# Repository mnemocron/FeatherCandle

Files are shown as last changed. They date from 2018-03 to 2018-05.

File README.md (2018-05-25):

# Feather Candle "_Guet Nacht - I Love You_"
## 15x7 LED matrix candle based on Adafruit Feather HUZZAH (ESP8266)

---

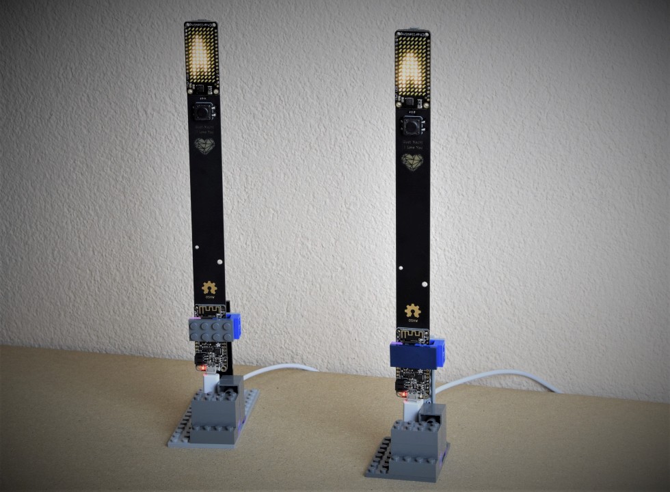
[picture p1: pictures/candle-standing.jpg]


## Introduction

This electronic project is intended as a romantic gimmik for two long distance lovers.
The candle is connected to the io.adafruit.com cloud over WiFi.

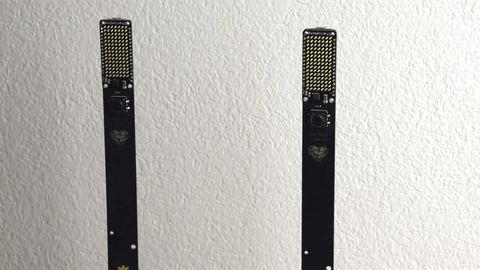
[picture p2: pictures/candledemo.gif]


> Whenever one person turns on their own candle, the candle of their lover - on the other side of the world - will light up as well.

The project is built around the Adafruit Feather boards and uses the 15x7 LED matrix and the WiFi enabled Feather HUZZAH board based on the ESP8266 microcontroller. The IoT handling is built around the MQTT service of [io.adafruit.com](https://io.adafruit.com).

### The Name

**_"Guet Nacht"_** is wishing a good night in Swiss German. When I was working on this project I said good night to my loved person by telling them _"Guet Nacht - I love you"_. Ultimately I decided that this is the codename for this project.

---

## Hardware

There are three different variants for the hardware configuration which ultimately determines the functionality and software capabilities. **Yes you can build just the candle without WiFi.**

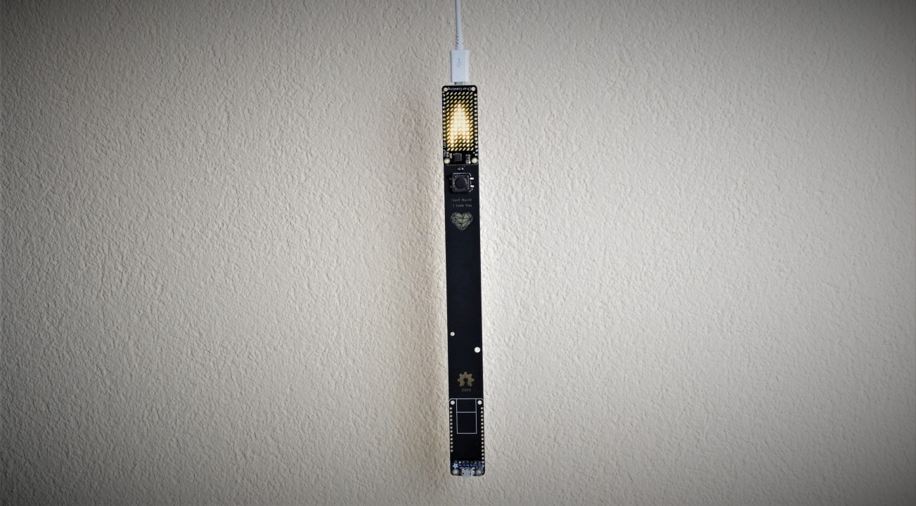
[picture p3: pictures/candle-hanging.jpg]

The candle can also be hung from the ceiling.

### Variant 1: Trinket (just the candle)

This is the most simple and straight forward variant. The essential parts are the [Adafruit 15x7 CharliePlex LED Matrix FeatherWing](https://www.adafruit.com/product/3163) and the [Adafruit Trinket M0](https://www.adafruit.com/product/3500).
This variant is just the candle powered over micro USB.
The micro USB connector is at the top (where the flame is) so the candle could be hanged from the ceiling. Alternatively you can add a [USB Micro-B Breakout Board](https://www.adafruit.com/product/1833) at the bottom of the board to power the candle at the socket.

### Variant 2: Feather (just the candle)

This variant is driven by any Feather board capable of compiling the candle animation sketch. The Feather boards provide an on-board battery charger. At the back of the candle's PCB there is space for a [Keystone 1042P](http://www.keyelco.com/product.cfm/product_id/918) battery holder for a 18650 3.7V battery (this feature is not tested).

### Variant 3: HUZZAH (WiFi enabled)

This is the original Idea. The Trinket holds the code for the flame animation while the Feather HUZZAH is connected to the Adafruit IO cloud. This variant can also be powered by a battery like variant 2. 

##### Battery

This feature remains **untested**. 
Also note that the ESP8266 uses a significant ammount of power, up to 170mA when transmitting data over Wifi ([source](https://bbs.espressif.com/viewtopic.php?t=133)). This may result in very short battery service life).

---

### Building Variant 3

#### Bill of materials (BOM)

This is the partlist for the WiFi enabled candle. 

| Description | Value | Manufacturer | Pcs. | Part. Nr. (mouser) | price (estimation) |
|---|---:|---|-----:|---:|---:|
| Candle PCB | - | - | 1 |  | $ 10.00 |
| 15x7 CharliePlex LED Matrix FeatherWing (warm white) | - | [Adafruit (3163)](https://www.adafruit.com/product/3163) | 1 | [485-3163](https://www.mouser.com/ProductDetail/Adafruit/3163?qs=%2fha2pyFaduh%252brbpYDT4hI1KcasFFaXTHrw3K2WUgkuI%3d) | $ 13.30 |
| Feather HUZZAH with ESP8266 WiFi | - | [Adafruit (2821)](https://www.adafruit.com/product/2821) | 1 | [485-2821](https://www.mouser.com/ProductDetail/Adafruit/2821?qs=%2fha2pyFadujIGPK6Sj3t4nFuChuwEnz5Imbr6Do1gT8%3d) | $ 18.00 |
| Trinket M0 | - | [Adafruit (3500)](https://www.adafruit.com/product/3500) | 1 | [485-3500](https://www.mouser.com/ProductDetail/Adafruit/3500?qs=%2fha2pyFadugsjdovVS3NFiBTcocohBou1VlJ%2f0Oc5Cc%3d) | $ 9.20 |
| 18650 battery clip SMT | - | [Keystone Electronics](http://www.keyelco.com/product.cfm/product_id/918) | (1) | [534-1042P](https://www.mouser.com/ProductDetail/Keystone-Electronics/1042P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) | $ 3.10 |
| 18650 Li-Ion battery 3.7V | - | - | (1) |  |  |
| Resistor SMD 1206 | 10k | - | 2 | 
 | $ 0.10 |
| Resistor SMD 1206 | 330R | - | 1 |  | $ 0.10 |
| LED 0805 | - | - | 1 |  |  |
| Pushbutton SMD 12mm | - | - | 1 | eg. [611-PTS125SK43SMTR2](https://www.mouser.com/ProductDetail/611-PTS125SK43SMTR2) | $ 0.50 |
| Pushbutton SMD 6.2mm | - | - | 1 | eg. [611-KSC701GLFS](https://www.mouser.com/ProductDetail/611-KSC701GLFS) | $ 0.50 |
| Capacitor SMD 1206 | 100uF | - | (2) |  |
| Capacitor SMD 0805 | 0.1uF | - | (2) |  |
| USB Micro-B Breakout Board | - |[Adafruit (1833)](https://www.adafruit.com/product/1833) | (1) | [485-1833](https://www.mouser.com/ProductDetail/Adafruit/1833?qs=sGAEpiMZZMsMyYRRhGMFNlzK0q9uz4bUWJaCPx97HuA%3d) | $ 1.50 |
| **Total** * |  |  |  |  | **~$ 50.00** |

> (* The prices are just an estimation. Especially the PCB can only be ordered in larger quantities (>5 pcs).)

> **Important:** The above parts are just for **one** board. In order to build the two connected candles each component is required twice the ammount listed.

> **Notes** 
> - You can either place a 12mm or a 6.2mm push button on the front. (You also need a 6.2mm button on the back).
> - The USB Micro-B Breakout Board is optional for the **variants 1 & 2** (not required on variant 3)
> - **optional**: the capacitors are not required
> - **optional**: the battery holder and the 18650 battery are optional (only work on a **feather variant (2 & 3)**)

#### PCB

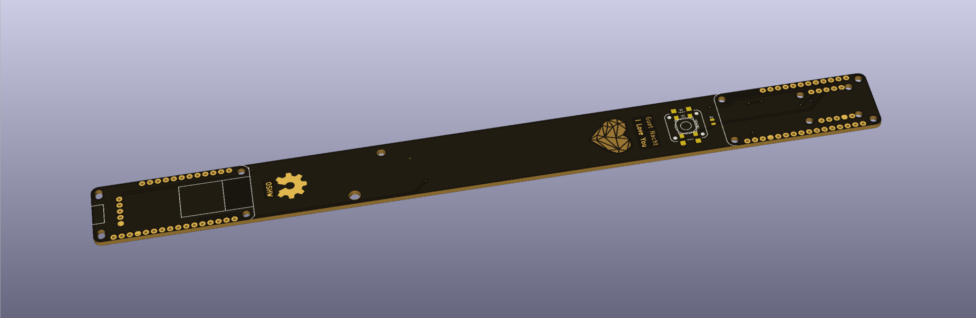
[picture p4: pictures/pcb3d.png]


You can download the manufacturing files (Gerbers) and use them to order the PCBs from a PCB manufacturer of choice. I recommend using **black solder mask** and **ENIG** surfacing.

Places where you can order custom circuit boards (selection):

> - [OSH Park](https://oshpark.com/)
> - [Aisler](https://aisler.net/products/boards)
> - [DirtyPCBs](http://dirtypcbs.com/store/pcbs)
> - [Elecrow](https://www.elecrow.com/pcb-manufacturing.html)
> - [JLCPCB](https://jlcpcb.com/quote)
> - [PCBCart](https://www.pcbcart.com/)
> - ([Aliexpress](https://www.aliexpress.com/category/521/pcb-pcba.html))

---

## Software

Setting up the Arduino IDE:

> - Download the [Arduitno IDE](https://www.arduino.cc/en/Main/Software)
> - How to up the [Adafruit Trinket M0](https://learn.adafruit.com/adafruit-trinket-m0-circuitpython-arduino/arduino-ide-setup)
> - How to up the [Adafruit Feather HUZZAH](https://learn.adafruit.com/adafruit-feather-huzzah-esp8266/using-arduino-ide)

#### Libraries

The following libraries are required to compile the software in the Arduino IDE.

> - [ESP8266 Arduino](https://github.com/esp8266/Arduino) 
> - [Adafruit IS31FL3731](https://github.com/adafruit/Adafruit_IS31FL3731) 
> - [Adafruit MQTT](https://github.com/adafruit/Adafruit_MQTT_Library) 
> - [Arduino Json](https://github.com/bblanchon/ArduinoJson) 
> - [Wifi Manager](https://github.com/tzapu/WiFiManager) 

### `FeatherCandleTrinket.ino`

This is the Arduino code for the Trinkete M0 which you will need for Variants 1 and 3.

**Note for Variant 1** (just the candle):
You might need to comment the `pinMode(PIN_ONOFF_WEB, INPUT);` on `line 68` so that the input isn't floating and randomly switching the flame on and off.

### `FeatherCandleFeather.ino`

This is the Arduino code soley for Variant 2 where the matrix is powered by any Feather microcontroller board.

### `FeatherCandleHuzzah.ino`

This is the Arduino code you need for the WiFi enabled Variant 3. This goes to the Feather HUZZAH board to connect to the Adafruit IO cloud and control the Trinket M0.

---

## Manual

### Setup the candle (WiFi)

The first time you turn on the candle you will have to configure the WiFi and the MQTT parameters. Luckily the software has a configuration portal built in, so you won't have to hardcode these parameters into the Arduino file.

> This way you can give away a candle to someone who does not know how to program.

### Signing up for Adafruit IO

You need to:
- create an Adafruit account
- log in to [io.adafruit.com](https://io.adafruit.com)
- create a new feed called `candle`

You need the following values to continue:
- `username` (find it on [accounts.adafruit.com](https://accounts.adafruit.com/))
- `key` (find it on [io.adafruit.com](https://learn.adafruit.com/mqtt-adafruit-io-and-you/getting-started-on-adafruit-io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))
- `feed` (the feed your just created: `candle`)

You can find more detailed instructions on how to get started with Adafruit IO on Adafruit's learning platform: [learn.adafruit.com](https://learn.adafruit.com/mqtt-adafruit-io-and-you/getting-started-on-adafruit-io)

**If you give away one candle to your lover:**

> **Important** Both candles require the same values for `username` / `key` / `feed` in order to be synchronized.

Your partner does not require an Adafruit account. Just give them your own `username` / `key` / `feed` so that they can set up their candle as follows:

#### To start the candle in configuration mode:

Hold the button on the back of the candle and turn on the feather candle. You can do this two ways:
- hold the button on the back then plug in the USB connector to power the device on
- hold the button on the back then press the reset button on the Feather HUZZAH itself while power is already on

finally release the button on the back.

Take your phone or computer and search for WiFi networks. You should see a network called `Feather Candle` - the password is `iloveyou`.

If you have successfully connected to the access point it should direct you to a "sign-in" page. If this does not happen just open your browser and open the webpage [10.0.1.1](http://10.0.1.1). On this page you have 4 buttons available.

##### `Info`

This page shows you the MAC address and other information about the ESP8266 that is on the Feather HUZZAH.

##### `Configure WiFi`

In the most cases this is the only page that you will need.

Choose a WiFi network on the list of available networks and enter the password.

**The ESP8266 only works with 2.4GHz networks.**

On this page you have a bunch of other values that you can configure.

| Name | Description | Default | need to change? |
|---|---|---:|---|
| `mqtt_server` | address to the MQTT server | `io.adafrtuit.com` | no |
| `mqtt_port` | MQTT server port | `1883` | no |
| `aio_key` | Adafruit IO key |  | yes |
| `aio_username` | Adafruit IO username |  | yes |
| `aio_feed` | Adafruit IO feed | `candle` | optional (*) |
| `aio_poll_interval` | interval to check for changes in [s] | `3` | optional (**) |
| `aio_last_will` | last value to send on disconnect | `0` | optional |

(*) the name of your Adafruit IO feed

(**) not implemented yet, see issues - default value is 3 seconds

---

## Inspiration

### mori.london

>mori.london sets out to define a completely new category of LED lighting: playful, emotional, atmospheric and elegant, always innovative and always low power and low impact on the environment.

[www.mori.london](https://www.mori.london/)

Developer: [Jaco Burge](http://jacoburge.co.uk/morilondon-candles/)

### My New Flame

by Moritz Waldemeyer & Ingo Maurer

[www.ingo-maurer.com](https://www.ingo-maurer.com/en/products/my-new-flame)

### Adafruit Animated Flame Pendant

> Turn on your heartlight.
Let it shine wherever you go.
Let it make a happy glow.
For all the world to see.

[learn.adafruit.com](https://learn.adafruit.com/animated-flame-pendant/overview)

---

#### Issues

- `[wontfix]` one of the through hole clips on the battery holder must be cut off in order to mount it on the backside of the PCB

#### ToDo

☐ test battery lifetime

☐ add secure api interface (https requests / port 8883 for SSL)

---

## Credits

- [wbphelps](https://github.com/wbphelps/FeatherCandle) - FeatherCandle Software for 15x7 Feather Wing LED matrix
- [Adafruit](https://learn.adafruit.com/animated-flame-pendant/overview) - Tutorial and software for the Flame Pendant
- [tzapu](https://github.com/tzapu/WiFiManager) - WiFiManager library and example code
- [bblanchon](https://github.com/bblanchon/ArduinoJson) - Arduino Json library

---

> Adafruit invests time and resources providing this open source design, please support Adafruit and open-source hardware by purchasing products from Adafruit!

---

## License

Creative Commons Attribution-ShareAlike 4.0 [CC BY-SA 4.0](https://creativecommons.org/licenses/by-sa/4.0/)

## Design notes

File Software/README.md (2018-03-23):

# Feather Candle Software

---

## Which file do I need for my candle?

### Variant 1: Trinket (just the candle)

You only need `FeatherCandleTrinket_standalone.ino` and upload it to your Trinket M0.

### Variant 2: Feather (just the candle)

You only need `FeatherCandleFeather.ino` and upload it to your Feather board of your choice.

### Variant 3: HUZZAH (WiFi enabled)

You need `FeatherCandleHUZZAH.ino` and upload it to the Feather HUZZAH board.
You also need `FeatherCandleTrinket.ino` and upload it to the Trinket M0.

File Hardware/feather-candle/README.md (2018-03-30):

# Feather Candle "_Guet Nacht - I Love You_"
## 15x7 LED matrix candle based on Adafruit Feather HUZZAH (ESP8266)

---

## Hardware

KiCAD project and gerber files.

__Note__

`feather-candle-gerbers-2018-02-23.zip` are the previous gerbers which contain some issues.

---

## License

Creative Commons Attribution-ShareAlike 4.0 [CC BY-SA 4.0](https://creativecommons.org/licenses/by-sa/4.0/)

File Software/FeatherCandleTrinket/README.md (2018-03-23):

# FeatherCandleTrinket

Original code by [wbphelps](https://github.com/wbphelps/FeatherCandle)

`convert.py` is changed to flip the images top to bottom before converting so that they lign up with the orientation of the FeatherWing matrix on the PCB.

---

Animated candle using Adafruit Feather and Adafruit CharliePlex FeatherWing 15x7 LED array

Clone of Adafruit/FirePendant, modified for the Feather.  Loops a canned animation sequence on the display.

Arduino sketch is comprised of `FeatherCandle.ino` and `data7x15flip.h` -- latter contains animation frames packed into PROGMEM array holding bounding rectangle + column-major pixel data for each frame (consumes most of the flash space on the ATmega328).

The `frames.zip` archive contains the animation source PNG images and a python script, convert.py, which processes all the source images into the required data.h format. The PNG images were generated via Adobe Premiere and Photoshop from Free Stock Video by user "dietolog" on [videezy.com](https://www.videezy.com/fire-and-smoke/788-candle-light-stock-video)

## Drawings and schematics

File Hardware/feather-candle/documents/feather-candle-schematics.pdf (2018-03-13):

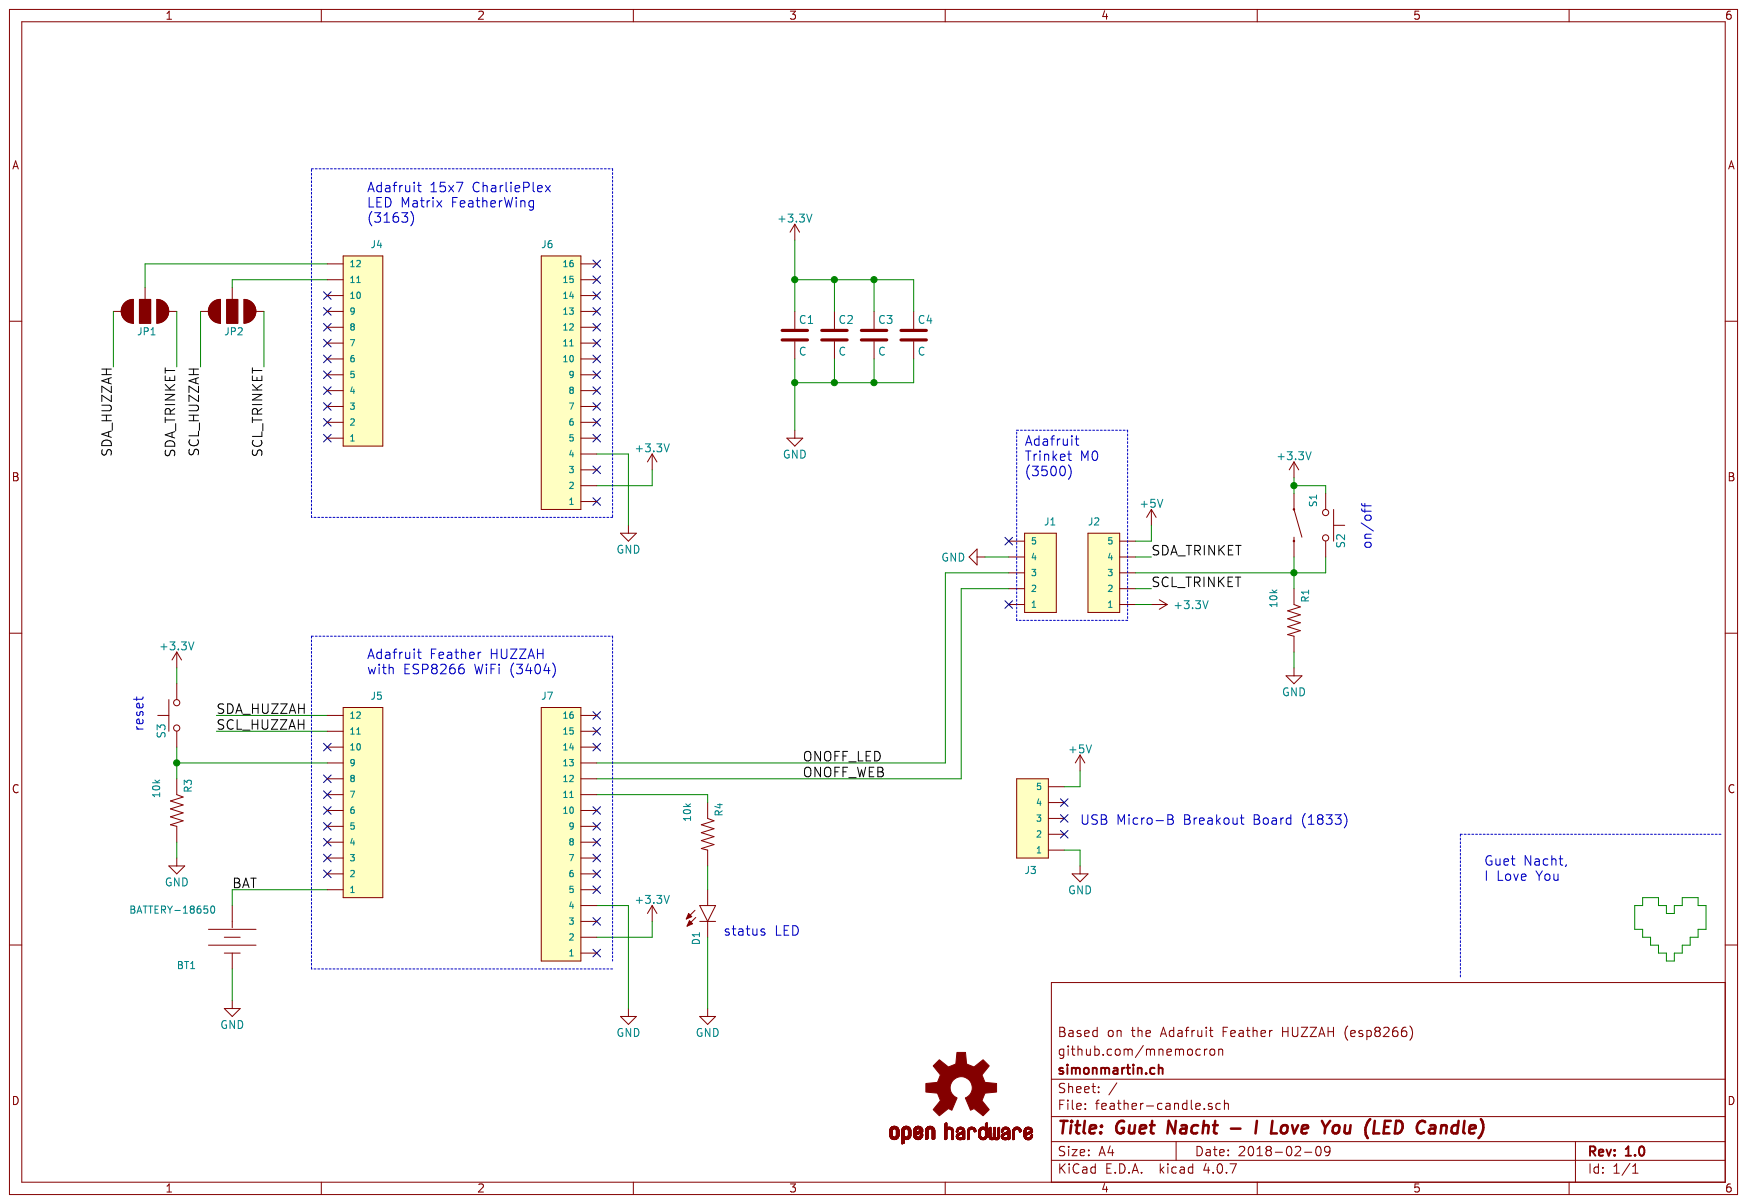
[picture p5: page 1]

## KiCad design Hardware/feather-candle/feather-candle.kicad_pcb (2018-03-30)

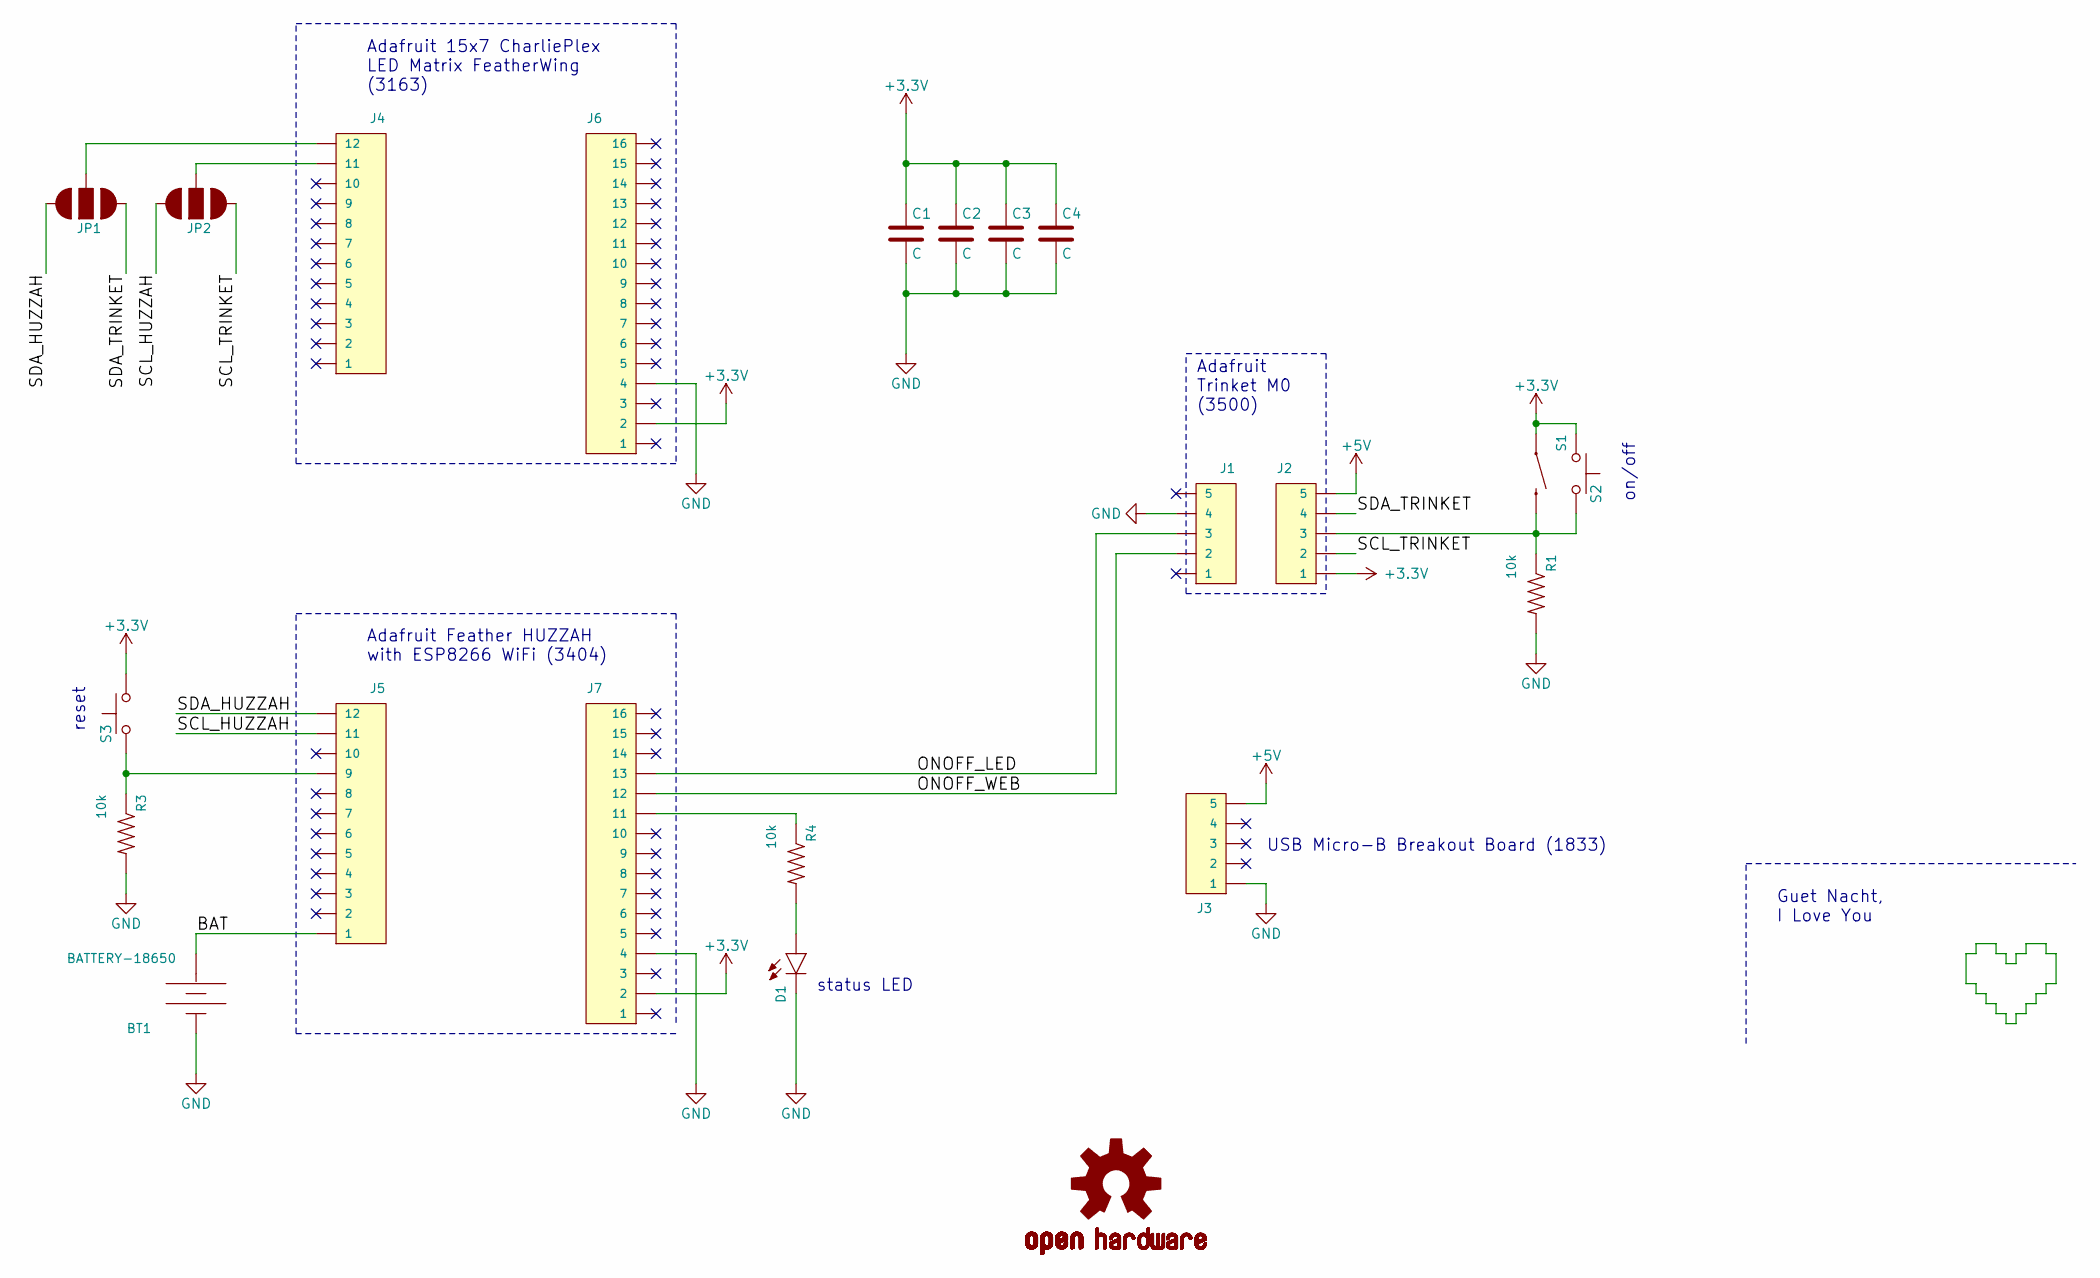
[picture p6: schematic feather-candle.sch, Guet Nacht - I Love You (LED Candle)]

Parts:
BT1: BATTERY-18650; BATTERY_18650-HOLDER_1042P
C1, C2: C; C_0805_HandSoldering
C3, C4: C; C_1210_HandSoldering
D1: LED-RED0603; LED-0603
J1, J2, J3: CONN_05; 1X05_NO_SILK
J4, J5: CONN_121X12_NO_SILK_KIT; 1X12_NO_SILK_KIT
J6, J7: CONN_161X16_NO_SILK; 1X16_NO_SILK
JP1, JP2: JUMPER-SMT_3_NO; SMT-JUMPER_3_NO_NO-SILK
LOGO1: OSHW-LOGOM; OSHW-Logo_12mm_copper
R1, R3, R4: 10k; 1206
S1: MOMENTARY-SWITCH-SPST-PTH-6.0MM; TACTILE_SWITCH_SMD_12MM
S2, S3: SW_Push; TACTILE_SWITCH_SMD_6.2MM_TALL

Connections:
+3V3: C1.1, C2.1, C3.1, C4.1, J2.1, J6.2, J7.2, S1.1, S2.1, S3.1
+5V: J2.5, J3.5
/BAT: BT1.PWR@ (+), J5.1
/ONOFF_LED: J1.3, J7.13
/ONOFF_WEB: J1.2, J7.12
/SCL_HUZZAH: J5.11, JP2.3
/SCL_TRINKET: J2.2, JP2.1
/SDA_HUZZAH: J5.12, JP1.3
/SDA_TRINKET: J2.4, JP1.1
GND: BT1.GND@ (-), C1.2, C2.2, C3.2, C4.2, D1.C, J1.4, J3.1, J6.4, J7.4, R1.2, R3.2
unnamed: D1.A, R4.2
unnamed: J2.3, R1.1, S1.3 (2), S2.2
unnamed: J4.11, JP2.2
unnamed: J4.12, JP1.2
unnamed: J5.9, R3.1, S3.2
unnamed: J7.11, R4.1

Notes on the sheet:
Guet Nacht, I Love You
Adafruit Feather HUZZAH with ESP8266 WiFi (3404)
status LED
USB Micro-B Breakout Board (1833)
on/off
Adafruit Trinket M0 (3500)
reset
Adafruit 15x7 CharliePlex LED Matrix FeatherWing (3163)

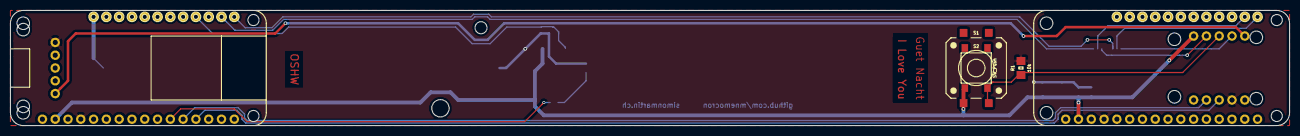
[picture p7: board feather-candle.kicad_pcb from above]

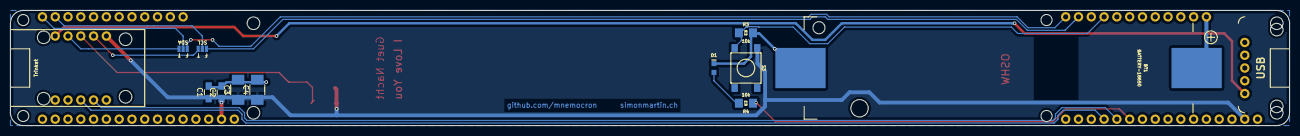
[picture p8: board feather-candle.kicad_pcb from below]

Board: 2 copper layers, 254.0 x 22.9 mm, 22 parts (14 on the bottom side), 16 nets.

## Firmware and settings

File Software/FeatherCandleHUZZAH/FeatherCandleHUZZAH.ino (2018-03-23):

/**
  * FeatherCandleHUZZAH.ino
  *
  * @file     FeatherCandleHUZZAH.ino
  * @author   Simon Burkhardt - github.com/mnemocron
  * @date     2018-03-23
  * @brief    This is the code for the WiFi part. It connects the candle to the Adafruit.io cloud.
  * @see      https://github.com/mnemocron/FeatherCandle
  * @details  This code uses two input pins. One is for the reset on startup button. The other input is to
  *           detect wether or not the candle was turned on by the Trinket M0.
  *           The output is used to signal state changes comming from the Adafruit server to the Trinket M0.
  *           This way the Trinket can control the state on the Adafruit server and the state on the Adafruit server
  *           can also be reflected back to the Trinket. 
  * @see      https://www.adafruit.com/product/3163
  * @note     using Adafruit Feather HUZZAH
  * @see      https://www.adafruit.com/product/3404
  *
  * @todo     make use of the onboard LED and the status LED
  */

#include <FS.h>                   // this needs to be first, or it all crashes and burns...

#include <ESP8266WiFi.h>          // https://github.com/esp8266/Arduino

//needed for library
#include <DNSServer.h>
#include <ESP8266WebServer.h>
#include <WiFiManager.h>          // https://github.com/tzapu/WiFiManager

#include "Adafruit_MQTT.h"
#include "Adafruit_MQTT_Client.h"
#include "ESP8266HTTPClient.h"

#include <ArduinoJson.h>          // https://github.com/bblanchon/ArduinoJson

// select which pin will trigger the configuration portal when set to LOW
// @see   https://learn.adafruit.com/adafruit-feather-huzzah-esp8266/pinouts
#define PIN_BTN 16
#define PIN_LED_ONBOARD 0
#define PIN_ONOFF_WEB 13
#define PIN_ONOFF_LED 12
#define PIN_LED_STATUS 14

// define your default values here, if there are different values in config.json, they are overwritten.
char mqtt_server      [34] = "io.adafruit.com";  // MQTT server
char mqtt_port        [6]  = "1883";             // use 8883 for SSL
char aio_key          [34] = "";                 // Adafruit IO key
char aio_username     [34] = "";                 // Adafruit username
char aio_feed         [34] = "candle";           // feed name
char aio_poll_interval[5]  = "3";                // http API request polling interval in [s]
char aio_last_will    [3]  = "0";                // value to publish on disconnect --> 0 = turn off candle

// aio_username[34] + "/feed/" + aio_feed[34]
char aio_publisher[34+34+9] = "";                // "url" to the Adafruit IO feed
// "http://io.adafruit.com/api/v2/" + aio_publisher[34+34+9] + "?X-AIO-Key=" + aio_key[34]
char api_uri[34+(34+34+9)+13+34] = "";           // uri used for http requests to the Adafruit IO API

uint32_t flame_on = LOW;    // candle on/off
uint32_t LED_reading = 0;   // edge detection for button
uint32_t LED_previous = 0;  // remember old button reading
long buttontime = 0;        // used for debounce time
long debounce = 100;        // debouce time in [ms]
uint32_t counter = 0;
uint32_t polling_delay = 3; // default to 3

// flag for saving data
bool shouldSaveConfig = true;

// callback notifying us of the need to save config
void saveConfigCallback () {
  Serial.println("Should save config");
  shouldSaveConfig = true;
}

WiFiClient client;
// or... use WiFiFlientSecure for SSL
//WiFiClientSecure client;

// Setup the MQTT client class by passing in the WiFi client and MQTT server and login details.
/** @note   dirty: just pass placeholder values to the constructor, since the MQTT library has no
  *         begin() method to later initialize the values loaded from flash
  */
Adafruit_MQTT_Client mqtt(&client, "io.adafruit.com", 1883, "placeholder", "somekey");
// Adafruit_MQTT_Client mqtt(&client, AIO_SERVER, AIO_SERVERPORT, AIO_USERNAME, AIO_KEY);

// Setup a feed called 'candlePublish' for publishing.
// Notice MQTT paths for AIO follow the form: <username>/feeds/<feedname>
/** @note   dirty: just pass placeholder values to the constructor, since the MQTT library has no
  *         begin() method to later initialize the values loaded from flash
  */
Adafruit_MQTT_Publish candlePublish = Adafruit_MQTT_Publish(&mqtt, "placeholder", MQTT_QOS_1);
// Adafruit_MQTT_Publish candlePublish = Adafruit_MQTT_Publish(&mqtt, AIO_PUBLISHER, MQTT_QOS_1);

// Bug workaround for Arduino 1.6.6, it seems to need a function declaration
// for some reason (only affects ESP8266, likely an arduino-builder bug).
void MQTT_connect();

void setup() {
  // put your setup code here, to run once:
  pinMode(PIN_BTN, INPUT);
  pinMode(PIN_ONOFF_WEB, OUTPUT);
  pinMode(PIN_ONOFF_LED, INPUT);
  pinMode(PIN_BTN, INPUT);
  pinMode(PIN_LED_ONBOARD, OUTPUT);
  Serial.begin(115200);
  Serial.println("Feather Candle");

  // clean FS, for testing
  // SPIFFS.format();
  
  /* END: READ JSON CONFIG */
  // read configuration from FS json
  Serial.println("mounting FS...");

  if (SPIFFS.begin()) {
    Serial.println("mounted file system");
    if (SPIFFS.exists("/config.json")) {
      /** @important needed if you add/change keys to the json file
        *            or else the ESP8266 it will throw an exception (28)
        */
      // SPIFFS.remove("/config.json");

      // file exists, reading and loading
      Serial.println("reading config file");
      File configFile = SPIFFS.open("/config.json", "r");
      if (configFile) {
        Serial.println("opened config file");
        size_t size = configFile.size();
        // Allocate a buffer to store contents of the file.
        std::unique_ptr<char[]> buf(new char[size]);

        configFile.readBytes(buf.get(), size);
        DynamicJsonBuffer jsonBuffer;
        JsonObject& json = jsonBuffer.parseObject(buf.get());
        json.printTo(Serial);
        if (json.success()) {
          Serial.println("\nparsed json");

          strcpy(mqtt_server,       json["mqtt_server"]);
          strcpy(mqtt_port,         json["mqtt_port"]);
          strcpy(aio_key,           json["aio_key"]);
          strcpy(aio_username,      json["aio_username"]);
          strcpy(aio_feed,          json["aio_feed"]);
          strcpy(aio_poll_interval, json["aio_poll_interval"]);
          strcpy(aio_last_will,     json["aio_last_will"]);

        } else {
          Serial.println("failed to load json config");
        }
      }
    }
  } else {
    Serial.println("failed to mount FS");
  }
  /* END: READ JSON CONFIG */

  /* BEGIN: RESET BUTTON PRESSED ON STARTUP */
  // user pressed the button on the board and restarted the Feather HUZZAH 
  // --> reset config and open access point 
  if ( digitalRead(PIN_BTN) == HIGH ) {
    // The extra parameters to be configured (can be either global or just in the setup)
    // After connecting, parameter.getValue() will get you the configured value
    // id/name placeholder/prompt default length
    WiFiManagerParameter custom_mqtt_server      ("server",   "mqtt server",                   mqtt_server,       34);
    WiFiManagerParameter custom_mqtt_port        ("port",     "mqtt port",                     mqtt_port,         6);
    WiFiManagerParameter custom_aio_key          ("key",      "AdafruitIO key",                aio_key,           34);
    WiFiManagerParameter custom_aio_username     ("username", "AdafruitIO username",           aio_username,      34);
    WiFiManagerParameter custom_aio_feed         ("feed",     "AdafruitIO feed",               aio_feed,          34);
    WiFiManagerParameter custom_aio_poll_interval("interval", "polling interval (s)",          aio_poll_interval, 5);
    WiFiManagerParameter custom_aio_last_will    ("will",     "\"last will\" (on disconnect)", aio_last_will,     3);

    // WiFiManager
    // Local intialization. Once its business is done, there is no need to keep it around
    WiFiManager wifiManager;

    // set config save notify callback
    wifiManager.setSaveConfigCallback(saveConfigCallback);
    // exit after config instead of connecting
    wifiManager.setBreakAfterConfig(true);
    // set static ip
    // wifiManager.setSTAStaticIPConfig(IPAddress(10,0,1,1), IPAddress(10,0,1,1), IPAddress(255,255,255,0));
    wifiManager.setAPStaticIPConfig(IPAddress(10,0,1,1), IPAddress(10,0,1,1), IPAddress(255,255,255,0));

    // add all your parameters here
    wifiManager.addParameter(&custom_mqtt_server);
    wifiManager.addParameter(&custom_mqtt_port);
    wifiManager.addParameter(&custom_aio_key);
    wifiManager.addParameter(&custom_aio_username);
    wifiManager.addParameter(&custom_aio_feed);
    wifiManager.addParameter(&custom_aio_poll_interval);
    wifiManager.addParameter(&custom_aio_last_will);

    //reset settings - for testing
    wifiManager.resetSettings();      // reset, because the button was pressed to load new values

    // set minimu quality of signal so it ignores AP's under that quality
    // defaults to 8%
    // wifiManager.setMinimumSignalQuality();
    
    // sets timeout until configuration portal gets turned off
    // useful to make it all retry or go to sleep
    // in seconds
    wifiManager.setTimeout(180);

    // fetches ssid and pass and tries to connect
    // if it does not connect it starts an access point with the specified name
    // here  "AutoConnectAP"
    // and goes into a blocking loop awaiting configuration
    if (!wifiManager.autoConnect("Feather Candle", "iloveyou")) {
      Serial.println("failed to connect and hit timeout");
      delay(3000);
      // reset and try again, or maybe put it to deep sleep
      ESP.reset();
      delay(5000);
    }

    // if you get here you have connected to the WiFi
    Serial.println("fetched...yeey :)");

    // read updated parameters
    strcpy(mqtt_server,       custom_mqtt_server.getValue());
    strcpy(mqtt_port,         custom_mqtt_port.getValue());
    strcpy(aio_key,           custom_aio_key.getValue());
    strcpy(aio_username,      custom_aio_username.getValue());
    strcpy(aio_feed,          custom_aio_feed.getValue());
    strcpy(aio_poll_interval, custom_aio_poll_interval.getValue());
    strcpy(aio_last_will,     custom_aio_last_will.getValue());

    // save the custom parameters to FS
    if (shouldSaveConfig) {
      Serial.println("saving config");
      DynamicJsonBuffer jsonBuffer;
      JsonObject& json = jsonBuffer.createObject();

      json["mqtt_server"]       = mqtt_server;
      json["mqtt_port"]         = mqtt_port;
      json["aio_key"]           = aio_key;
      json["aio_username"]      = aio_username;
      json["aio_feed"]          = aio_feed;
      json["aio_poll_interval"] = aio_poll_interval;
      json["aio_last_will"]     = aio_last_will;

      File configFile = SPIFFS.open("/config.json", "w");
      if (!configFile) {
        Serial.println("failed to open config file for writing");
      }

      json.printTo(Serial);
      json.printTo(configFile);
      configFile.close();
      // end save
    }
    ESP.reset();  // reset the chip
    delay(3000);
  }
  /* END: RESET BUTTON PRESSED ON STARTUP */
  uint16_t aio_port = 0;
  if(strcmp(mqtt_port, "1883") == 0) aio_port = 1883;
  if(strcmp(mqtt_port, "8883") == 0) aio_port = 8883;

  /** @todo   add char[] to int parse for the polling interval time
    *         to set the counter time in the loop()
    */

  Serial.println("Initialize MQTT client:");
  Serial.print(mqtt_server);  Serial.print(":");   Serial.println(aio_port);
  Serial.print(aio_username); Serial.print(" / "); Serial.println(aio_key);
  mqtt = Adafruit_MQTT_Client(&client, mqtt_server, aio_port, aio_username, aio_key);
  
  // Connect to WiFi access point.
  Serial.println(); Serial.println();
  Serial.print("Connecting to WiFi");

  WiFi.begin();    // connects to last known access point (values in flash)
  while (WiFi.status() != WL_CONNECTED) {
    delay(500);
    Serial.print(".");
  }
  Serial.println();

  Serial.println("WiFi connected");
  Serial.println("IP address: "); Serial.println(WiFi.localIP());

  strcat(aio_publisher, aio_username);
  strcat(aio_publisher, "/feeds/");
  strcat(aio_publisher, aio_feed);
  Serial.println("Initialize MQTT publisher:");
  Serial.println(aio_publisher);
  candlePublish = Adafruit_MQTT_Publish(&mqtt, aio_publisher, MQTT_QOS_1);

  mqtt.will(aio_publisher, aio_last_will);
  strcat(api_uri, "http://io.adafruit.com/api/v2/");
  strcat(api_uri, aio_publisher);
  strcat(api_uri, "?X-AIO-Key=");
  strcat(api_uri, aio_key);

  polling_delay = atoi(aio_poll_interval);
  if(polling_delay < 1)   polling_delay = 1;
  if(polling_delay > 100) polling_delay = 100;
}

void loop() {
  // Ensure the connection to the MQTT server is alive (this will make the first
  // connection and automatically reconnect when disconnected).  See the MQTT_connect
  // function definition further below.
  MQTT_connect();

  /** @todo   adjust this value to the polling_interval value in seconds
    */
  if(counter > polling_delay){
  	Serial.print("Polling Interval: "); Serial.println(atoi(aio_poll_interval));
    counter = 0;
    if (WiFi.status() == WL_CONNECTED) {
      // Serial.println("getting update...");
      HTTPClient http;
      // Serial.println(api_uri);
      http.begin( api_uri  );
      int httpCode = http.GET();
      if (httpCode > 0) { //Check the returning code
        String payload = http.getString();   //Get the request response payload
        // Serial.println(payload);          //Print the response payload
        const size_t bufferSize = JSON_OBJECT_SIZE(2) + JSON_OBJECT_SIZE(3) + JSON_OBJECT_SIZE(5) + JSON_OBJECT_SIZE(8) + 370;
        DynamicJsonBuffer jsonBuffer(bufferSize);
        JsonObject& jsonResponse = jsonBuffer.parseObject(payload);
        // Serial.println((int)jsonResponse["id"]);
        int last_value = jsonResponse["last_value"];
        // Serial.println(last_value);
        if(last_value != flame_on){
          flame_on = last_value;
          Serial.print(F("Value Update: "));
          Serial.println(last_value);
        }
      }
      http.end();
    }
  }

  LED_reading = digitalRead(PIN_ONOFF_LED);
  // rising edge from the Trinket  --> Candle was turned ON on by the button
  if(LED_reading == HIGH && LED_previous == LOW && millis() - buttontime > debounce){
    flame_on = true;
    buttontime = millis();
    Candle_SendUpdate(flame_on);
  }
  // falling edge from the Trinket  --> Candle was turned ON on by the button
  if(LED_reading == LOW && LED_previous == HIGH && millis() - buttontime > debounce){
    flame_on = false;
    buttontime = millis();
    Candle_SendUpdate(flame_on);
  }
  LED_previous = LED_reading;
  digitalWrite(PIN_ONOFF_WEB, flame_on);
  
  // ping the server to keep the mqtt connection alive
  // NOT required if you are publishing once every KEEPALIVE seconds
  if(! mqtt.ping()) {
    mqtt.disconnect();
  }
  delay(1000);
  counter ++;
}

// Function to connect and reconnect as necessary to the MQTT server.
// Should be called in the loop function and it will take care if connecting.
void MQTT_connect() {
  int8_t ret;

  // Stop if already connected.
  if (mqtt.connected()) {
    return;
  }

  Serial.print("Connecting to MQTT... ");

  uint8_t retries = 3;
  while ((ret = mqtt.connect()) != 0) { // connect will return 0 for connected
       Serial.println(mqtt.connectErrorString(ret));
       Serial.println("Retrying MQTT connection in 5 seconds...");
       mqtt.disconnect();
       delay(5000);  // wait 5 seconds
       retries--;
       if (retries == 0) {
         // basically die and wait for WDT to reset me
         while (1);
       }
  }
  Serial.println("MQTT Connected!");
}


void Candle_SendUpdate(uint32_t value){
  // Now we can publish stuff!
  Serial.print(F("\nSending candlePublish val "));
  Serial.print(value==1? "1" : "0");
  Serial.print("...");
  for(int i=0; i<1; i++){
    if (! candlePublish.publish(value==1? "1" : "0")) {
      Serial.println(F("Failed"));
    } else {
      Serial.println(F("OK!"));
    }
    delay(7);
  }
}

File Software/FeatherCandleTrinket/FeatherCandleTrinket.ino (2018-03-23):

/**
  * FeatherCandleTrinket.ino
  *
  * @file     FeatherCandleTrinket.ino
  * @author   Simon Burkhardt - github.com/mnemocron
  * @date     2018-02-16
  * @brief    This is the code for the animation part of the feather candle
  * @see      https://github.com/mnemocron/FeatherCandle
  * 
  * @details  This code can be use to drive an Adafruit 15x7 CharliePlex LED Matrix FeatherWing
  *           with an Adafrtuit Trinket M0. This code uses one output pin to signal the state of the flame
  *           to the HUZZAH. There are two inputs. One is connected to a pushbutton to turn on/off the flame.
  *	          The other input is connected to the HUZZAH and listens to state changes on the Adafruit.io server.
  *           Original code for the flame animation by wbphelps on github.
  * @see      https://www.adafruit.com/product/3163
  * @see      https://github.com/wbphelps/FeatherCandle
  * @see      https://learn.adafruit.com/animated-flame-pendant/overview
  * 
  * @note     using Adafruit Trinket M0
  * @see      https://www.adafruit.com/product/3500
  */

#include <Adafruit_IS31FL3731.h>    // https://github.com/adafruit/Adafruit_IS31FL3731
#include "data7x15flip.h"           // Flame animation data
/* @note   convert.py is changed to flip the images top to bottom before converting
 *         so that they lign up with the orientation of the FeatherWing matrix
 */

// @see   https://learn.adafruit.com/adafruit-trinket-m0-circuitpython-arduino/pinouts
// #define PIN_SDA       0       // pin is reserved for TWI/I2C
#define    PIN_BTN       1
// #define PIN_SCL       2       // pin is reserved for TWI/I2C
#define    PIN_ONOFF_WEB 3
#define    PIN_ONOFF_LED 4

// using the FeatherWing version
Adafruit_IS31FL3731_Wing leds = Adafruit_IS31FL3731_Wing();

uint8_t        page = 0;     // Front/back buffer control
const uint8_t *ptr  = anim;  // Current pointer into animation data
const uint8_t  w    = 7;     // image width
const uint8_t  h    = 15;    // image height
uint8_t        img[w*h];     // Buffer for rendering image

bool flameOn = false;        // candle on/off
uint32_t BTN_reading = LOW;  // edge detection for button
uint32_t BTN_previous = LOW; // remember old button reading
uint32_t WEB_reading = LOW;  // edge detection for HUZZAH
uint32_t WEB_previous = LOW; // remember old HUZZAH reading
long buttontime_btn = 0;     // used for debounce time
long buttontime_web = 0;     // used for debounce time
long debounce = 100;         // debouce time in [ms]

/* SETUP FUNCTION - RUNS ONCE AT STARTUP --------------------------------------------------- */
void setup() {
//  Serial.begin(57600);
//  delay(100);
//  Serial.println("Trinket Candle");

  if (! leds.begin()) {
//    Serial.println("IS31 not found");
    while (1);
  }
  pinMode(PIN_BTN, INPUT);
  /* @todo   test INPUT_PULLUP with and without Feather HUZZAH */
  // pinMode(PIN_ONOFF_WEB, INPUT_PULLUP);  // pull up for standalone Trinket (w/o Feather HUZZAH)
  pinMode(PIN_ONOFF_WEB, INPUT);
  pinMode(PIN_ONOFF_LED, OUTPUT);
}

/* LOOP FUNCTION - RUNS EVERY FRAME -------------------------------------------------------- */
void loop() {
  BTN_reading = digitalRead(PIN_BTN);
  WEB_reading = digitalRead(PIN_ONOFF_WEB);
  if(BTN_reading == HIGH && BTN_previous == LOW && (millis() - buttontime_btn) > debounce){
    buttontime_btn = millis();
    flameOn = !flameOn;
//    if(flameOn) Serial.println("Flame On!");
//    else Serial.println("Flame Off!");
    ptr = anim;    // restart the animation at the first frame
  }
  // rising edge from the HUZZAH  --> Candle was turned ON on the Adafruit IO feed
  if(WEB_reading == HIGH && WEB_previous == LOW && (millis() - buttontime_web) > debounce){
    flameOn = true;
    buttontime_web = millis();
//    Serial.println("Flame On!");
    ptr = anim;    // restart the animation at the first frame
  }
  // falling edge from the HUZZAH --> Candle was turned OFF on the Adafruit IO feed
  if(WEB_reading == LOW && WEB_previous == HIGH && (millis() - buttontime_web) > debounce){
    flameOn = false;
    buttontime_web = millis();
//    Serial.println("Flame Off!");
  }
  BTN_previous = BTN_reading;
  WEB_previous = WEB_reading;

  if(flameOn){
    digitalWrite(PIN_ONOFF_LED, HIGH);    // signal to the HUZZAH that the flame is ON
    /* BEGIN: ANIMATION SECTION */
    uint8_t  a, x1, y1, x2, y2, x, y;
    // read NEXT frame.  Start by getting bounding rect for new frame:
    a = pgm_read_byte(ptr++);     // New frame X1/Y1
    if(a >= 0x90) {               // EOD marker? (valid X1 never exceeds 8)
      ptr = anim;                 // Reset animation data pointer to start
      a   = pgm_read_byte(ptr++); // and take first value
    }
    x1 = a >> 4;                  // X1 = high 4 bits
    y1 = a & 0x0F;                // Y1 = low 4 bits
    a  = pgm_read_byte(ptr++);    // New frame X2/Y2
    x2 = a >> 4;                  // X2 = high 4 bits
    y2 = a & 0x0F;                // Y2 = low 4 bits

    // Read rectangle of data from anim[] into portion of img[] buffer
    for(uint8_t y=y1; y<=y2; y++)
      for(uint8_t x=x1; x<=x2; x++) { 
        img[y*w + x] = pgm_read_byte(ptr++);
    }

    page ^= 1; // Flip front/back buffer index
    leds.setFrame(page);

    int i = 0;
    for (uint8_t x=0; x<h; x++) {
      for (uint8_t y=0; y<w; y++) {
        leds.drawPixel(x, y, img[i++]);  
      }
    }

    leds.displayFrame(page);
    /* END: ANIMATION SECTION */
  } else {
    digitalWrite(PIN_ONOFF_LED, LOW);    // signal to the HUZZAH that the flame is OFF
    leds.clear();
  }
}

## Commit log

2018-03-13 initial commit (wip)
    [feather-candle.sch]
2018-03-25 Fixed several issues with the PCB layout. Correct hole placement of the 1042 battery holder. Correct mounting hole placement of the Feather boards. Changed resistor footprints to 1206 and 0805_HandSo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
    [feather-candle.kicad_pcb, feather-candle.sch]
2018-03-30 first release
    [feather-candle.kicad_pcb]
